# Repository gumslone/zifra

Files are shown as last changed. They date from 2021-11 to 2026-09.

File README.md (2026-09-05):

<a href="https://www.buymeacoffee.com/gumslone" target="_blank">Buy Me A Coffee</a>

# ZIFRA

**ZIFRA** is an open-source **single-tube nixie clock**: one Soviet-era **IN-12B nixie tube**
spells the time out digit by digit. Powered by an **ESP8266 (ESP8285)**, it syncs its time
over WiFi via **NTP**, keeps time offline with a **DS3231 RTC**, rings up to three alarms
with selectable melodies, and is configured from a **mobile-friendly web interface** —
no app needed. <a href="https://www.youtube.com/watch?v=uE2CU6pZ4Vk" target="_blank">Watch it in action</a>.



### Order

Want one without soldering? Check the
<a href="https://www.tindie.com/stores/gumslone/" target="_blank">gumslone store on Tindie</a> —
or build your own: the firmware, web interface and 3D-printable enclosure are all in this repo.

### Features:
- built-in RTC (real-time clock) chip for accurate time when ZIFRA is used offline.
- Network Time Protocol (NTP) for very accurate time in online mode.
- automatic summer/winter time switching (European and US daylight-saving rules).
- built-in buzzer with up to 3 alarms and selectable melodies (shake ZIFRA to mute a ringing alarm).
- night sleep window that turns the nixie tube off at night (shake to show the time for 3 minutes during sleep).
- mobile-friendly configuration web interface, served by the clock itself at
  http://zifra.local — no app, no cloud, works on any LAN.
- firmware updates over WiFi, straight from the web interface (optionally password-protected).

### Web interface

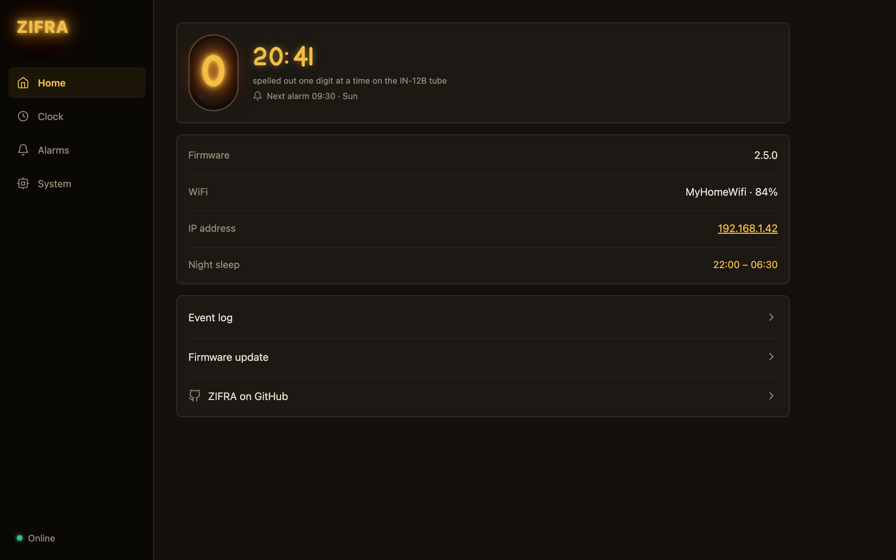
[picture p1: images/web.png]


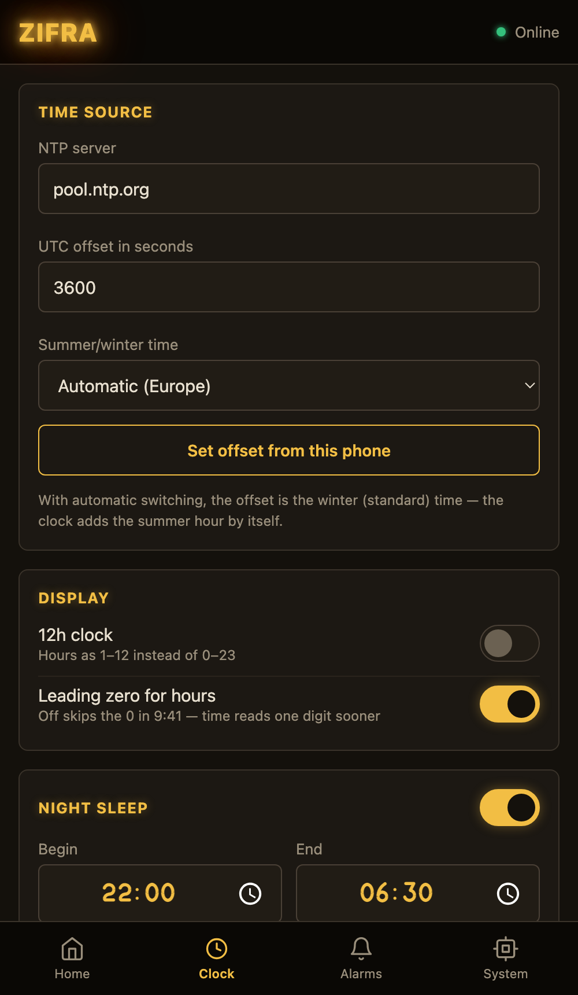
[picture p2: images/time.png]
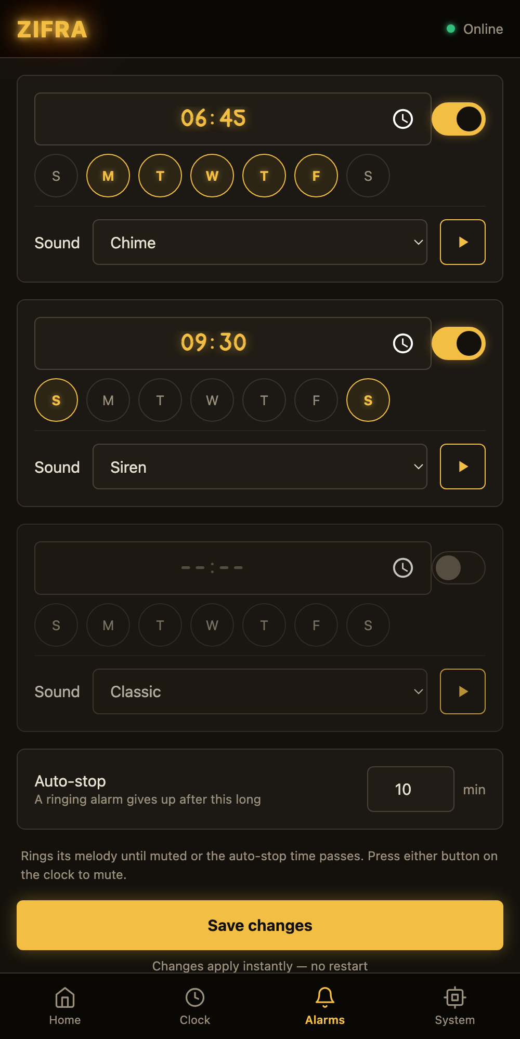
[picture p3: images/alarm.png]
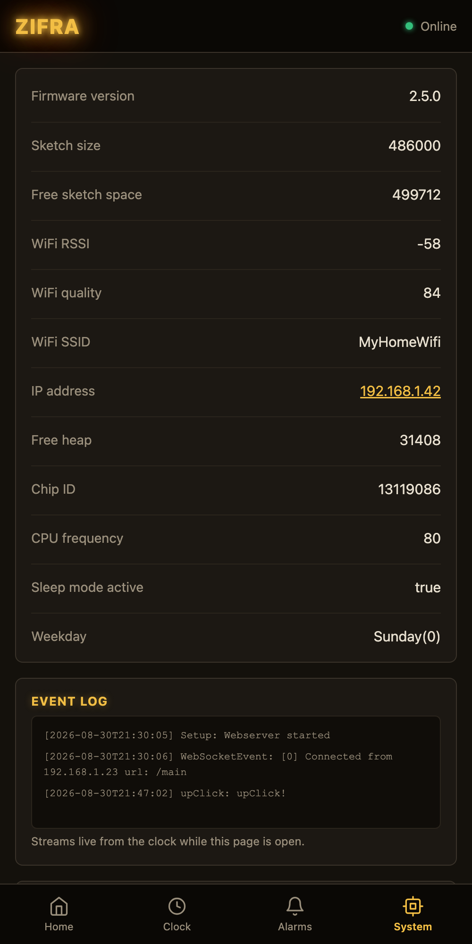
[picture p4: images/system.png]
  

### First-time setup

1. **Power the clock** with a 5 V USB power supply. On the first boot the tube cycles
   once through all digits and the buzzer plays a short jingle.
2. **Connect it to your WiFi.** With no network configured, ZIFRA opens its own
   access point named `ZIFRA-XXXXXX`. Join it with your phone and the setup portal
   opens by itself (if not, browse to `192.168.4.1`). Pick your network, enter the
   password, and save — the clock reboots and joins your WiFi. The portal stays up
   for 3 minutes; after that the clock restarts and tries again.
3. **Open the web interface** at http://zifra.local (or the clock's IP address,
   which your router's device list shows). The dashboard displays the firmware
   version, WiFi quality, IP and a live demo of what the tube is doing.
4. **Set your time zone** on the *Clock* page: tap *Set offset from this phone*, pick
   your summer/winter rule (Europe/USA) — with automatic switching on, the stored
   offset is the winter (standard) time and the clock adds the summer hour itself.
   Saving applies instantly, no restart needed.

No WiFi where the clock lives? Configure it once anywhere, then it keeps time on its
DS3231 RTC even with WiFi off.

### Everyday use

- **Reading the time** — the single tube spells the time digit by digit:
  hours' tens, hours' ones, then (with the decimal dot lit) minutes' tens and
  minutes' ones, followed by a longer dark pause before the next round. With the
  leading zero turned off, `09:41` starts straight at the `9` and reads one digit
  sooner.
- **Alarms** — up to three, each with its own weekdays and melody (preview the
  melodies right in the web UI). A ringing alarm stops when muted or after the
  configurable auto-stop time. **Shake the clock or press its button to mute.**
- **Night sleep** — the tube goes dark during the configured window (it may span
  midnight, e.g. 22:00–06:30). Shake the clock to light the time up for 3 minutes.
  The dashboard shows when the clock is asleep.
- **WiFi on/off** — shake the clock continuously for about 10 seconds to toggle
  WiFi (it restarts and runs offline from the RTC).
- **Factory reset** — hold the button for 35 seconds: settings and WiFi
  credentials are wiped and the setup portal opens again.
- **Firmware updates** — pick a release `.bin` on the *System* page and flash it
  right there, over WiFi. Settings survive updates. Set an *update password* on
  the same page if other people share your network (user name `zifra`).

### Firmware downloads

The repo ships only the stock board's release binary,
`firmware/zifra_esp8285.bin`. Every [release](https://github.com/gumslone/zifra/releases)
carries all four variants as downloadable assets:

- `zifra_esp8285_<version>.bin` — stock ZIFRA board (ESP8285)
- `zifra_esp8266_generic_<version>.bin` — generic 1M ESP8266 modules (ESP-01S, ESP-12, ...)
- `..._debug.bin` — same, with serial logging on 115200 baud

Building locally with `./build.sh all` puts all four under
`.build/<board>/<release|debug>/zifra.ino.bin`.

### Flashing over USB

For the first flash (or to recover a clock that can't reach the web updater),
ZIFRA bundles [BugZapper](https://github.com/gumslone/bugzapper) — a flasher with
a built-in serial monitor — as a git submodule under `tools/bugzapper`. esptool
is bundled, so it needs nothing but `python3`.

Clone with submodules (or pull it in afterwards):

```sh
git clone --recurse-submodules https://github.com/gumslone/zifra.git
# already cloned?
git submodule update --init
```

Then, from the repo root:

```sh
./flash.sh        # flash the bundled firmware/zifra_esp8285.bin (-f for another)
./flash.sh -l     # list detected serial ports
./bugzapper.sh    # GUI flasher + serial monitor (needs python3 with tkinter)
```

### Development

The firmware is a single Arduino sketch ([`zifra/zifra.ino`](zifra/zifra.ino)) with
its modules as headers under [`zifra/src/`](zifra/src) — pure logic (alarms, sleep
window, melodies, daylight-saving rules) is separated from hardware code so it can
be tested on the host:

```sh
./build.sh all     # arduino-cli builds: esp8285 + generic, release + debug
pio run            # or build with PlatformIO
./tests/run.sh     # native host tests (+ the web app's, if node is installed)
./tests/tidy.sh    # clang-tidy static analysis
```

Mind the flash budget: on the 1 MB layout an OTA image has to fit above the
running sketch, so a release binary bigger than about 479 KB could never be
updated over WiFi again — `build.sh` refuses to build one.

The web interface lives in [`web/v2/`](web/v2) — a dependency-free ES6 single-page
app in layered modules (`core` / `state` / `view` / `audio` / `app`). The clock
serves it itself: `tools/web/gzip_pages.py` (run by `build.sh`) bundles the JS and
CSS together with the pages in [`zifra/pages/`](zifra/pages) into gzipped PROGMEM
arrays in `Webinterface.h`, so no external hosting is involved. The same bundles
are also published at tehybug.com for firmware older than 2.5. The "Zifra Tube"
nixie webfont the UI uses is generated by
[`tools/font/build_font.py`](tools/font/build_font.py). CI builds every push and
publishes tagged releases from `zifra/src/version.h`.

### A short history of the nixie tube

Long before LEDs, numbers glowed in neon. The **nixie tube** is a cold-cathode
display from the 1950s: a glass envelope filled with neon holds a stack of ten
thin metal cathodes, each shaped like a digit, behind a wire-mesh anode. Apply
~170 V to one cathode and the gas around it ionizes — the digit is wrapped in the
soft orange glow of the neon discharge. Because the digits sit physically behind
one another, each one lights at its own depth inside the glass, which gives nixies
their unmistakable, slightly floating look.

Burroughs Corporation trademarked the name **Nixie** (from "Numeric Indicator
eXperimental No. 1") in 1955, and through the 1960s nixies were *the* readout of
serious machines: frequency counters, multimeters, desktop calculators, elevator
floor indicators, even mission-control consoles. By the mid-1970s cheaper,
lower-voltage vacuum-fluorescent displays and LEDs had displaced them in the
West — but factories in the Soviet Union kept producing their own **ИН (IN)
series** in enormous numbers well into the 1980s.

The tube in ZIFRA is one of those: the **IN-12B (ИН-12Б)**, a side-viewed nixie
with 18 mm digits and a decimal point on the left, made mainly by Reflector in
Saratov. Other IN-series tubes came from plants across the Soviet Union — the
Gazotron works in Rivne, Ukraine was among the biggest, producing the IN-8,
IN-14 and IN-16 that power many of today's nixie clocks. Unsocketed "new old stock" tubes still surface from old
warehouses, which is what keeps nixie clocks alive today — nobody mass-produces
nixies anymore, so every tube is decades old and finite. That scarcity is also why
ZIFRA uses a **single tube** that spells the time digit by digit instead of four
in a row: one tube to source, one tube to someday replace, and a clock that makes
a little ceremony out of every minute. The night-sleep window exists for the same
reason — a resting tube is a tube that lasts: powered sensibly, an IN-12B is good
for years of continuous glow, and cycling through all ten digits (as ZIFRA does at
startup) helps keep unused cathodes clean.

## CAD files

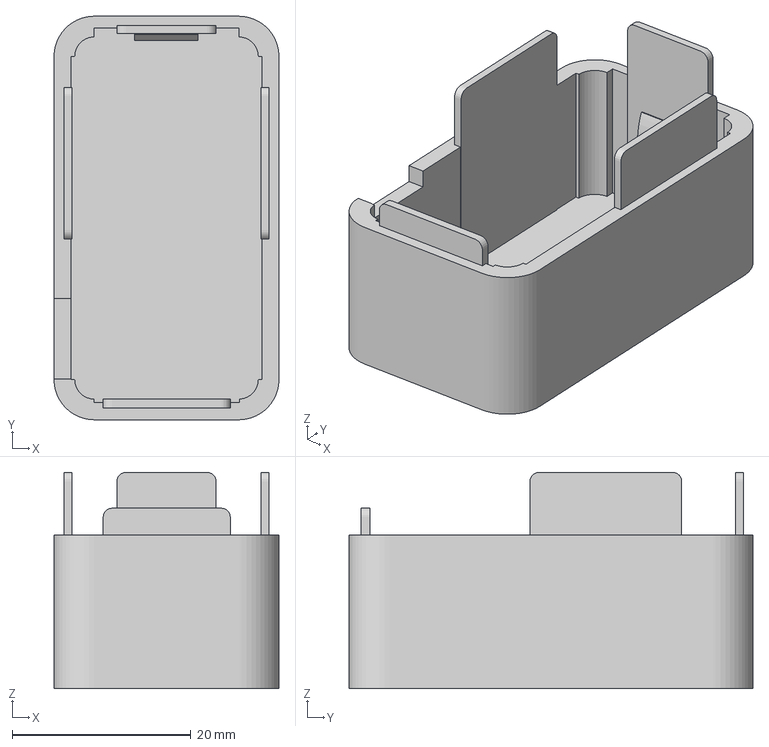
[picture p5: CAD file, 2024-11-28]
enclosure/nixie_back.3mf
25.2 x 45.2 x 24.2 mm

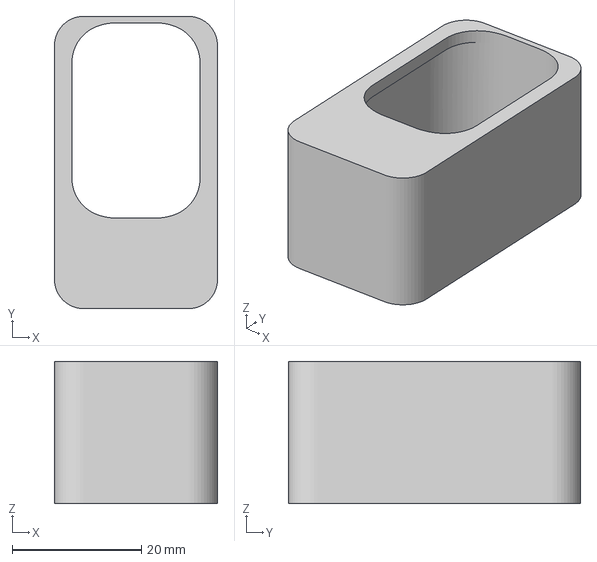
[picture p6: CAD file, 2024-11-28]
enclosure/nixie_front.3mf
25.2 x 45.2 x 22.0 mm

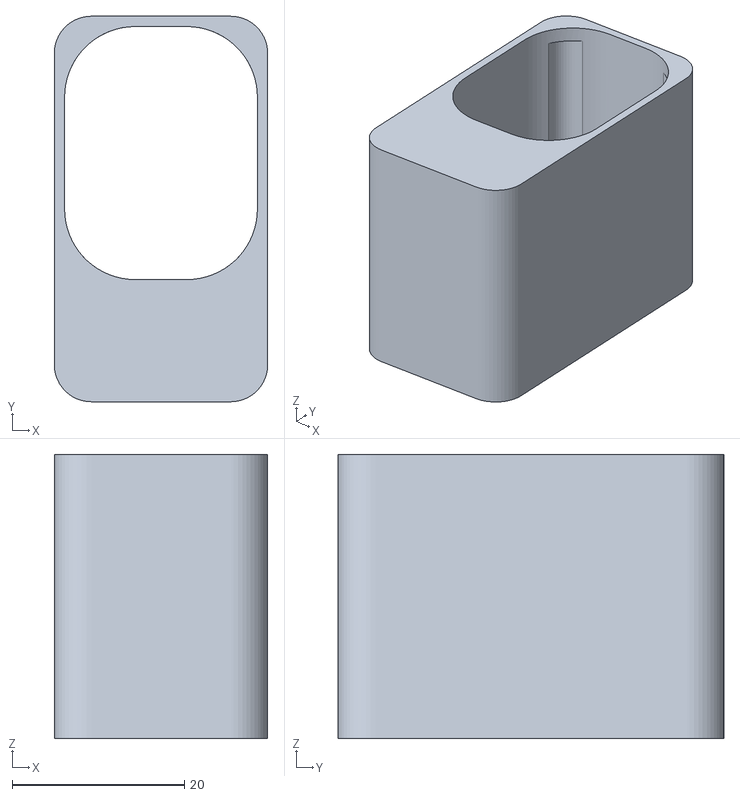
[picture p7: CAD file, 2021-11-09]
enclosure/front_v1.stl
24.8 x 44.8 x 33.0

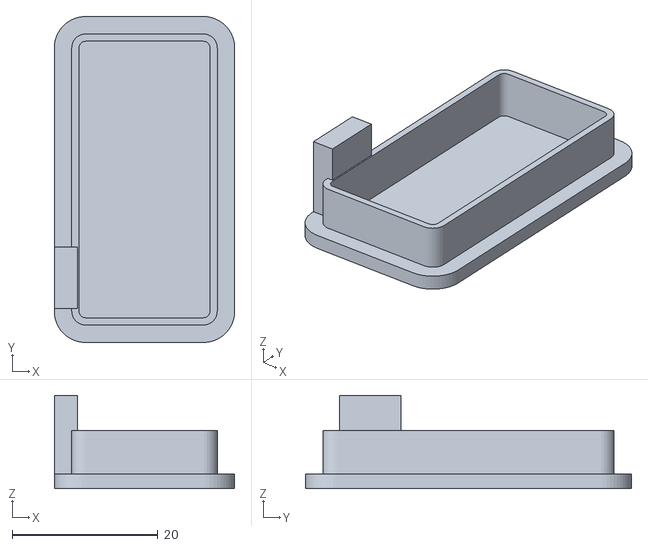
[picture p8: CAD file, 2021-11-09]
enclosure/back_v1.stl
24.8 x 44.8 x 12.8

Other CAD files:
enclosure/nixie_back.stl
enclosure/nixie_front.stl

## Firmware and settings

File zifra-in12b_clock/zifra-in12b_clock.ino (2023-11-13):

// #include <ArduinoOTA.h>
#include <ArduinoJson.h> // V5.13.5!!!
#include <ESP8266HTTPClient.h>
#include <ESP8266HTTPUpdateServer.h>
#include <ESP8266WebServer.h>
#include <ESP8266WiFi.h>
#include <ESP8266mDNS.h>
#include <EasyButton.h>
#include <FS.h>
#include <NTPClient.h>
#include <TickerScheduler.h>
#include <WebSocketsServer.h>
#include <WiFiClient.h>
#include <WiFiManager.h>
#include <WiFiUdp.h>
#include <Wire.h>
#include <ds3231.h>

#define DEBUG 1

#if DEBUG
#define D_SerialBegin(...) Serial.begin(__VA_ARGS__)
#define D_print(...) Serial.print(__VA_ARGS__)
#define D_write(...) Serial.write(__VA_ARGS__)
#define D_println(...) Serial.println(__VA_ARGS__)
#else
#define D_SerialBegin(...)
#define D_print(...)
#define D_write(...)
#define D_println(...)
#endif

#include "Tools.h"
#include "Webinterface.h"
#include "i2cscanner.h"
#include "pitches.h"
// notes in the melody:
int melody[] = {NOTE_C4, NOTE_G3, NOTE_G3, NOTE_A3,
                NOTE_G3, 0,       NOTE_B3, NOTE_C4};

// note durations: 4 = quarter note, 8 = eighth note, etc.:
int noteDurations[] = {4, 8, 8, 4, 4, 4, 4, 4};

struct ts t; // for ds2320 rtc time

char identifier[24];

// Set I2C address
int address = 0x20;

byte a = B00000000;
byte b = B00000000;

long utcOffsetInSeconds = 2 * 3600;

char daysOfTheWeek[7][12] = {"Sunday",   "Monday", "Tuesday", "Wednesday",
                             "Thursday", "Friday", "Saturday"};

uint8_t val1 = 0;
uint8_t val2 = 0;
uint8_t val3 = 0;
uint8_t val4 = 0;
uint8_t val5 = 0;
uint8_t val6 = 0;

int Year, Month, Day, Hour, Minute, Second;

// Define NTP Client to get time
String ntpServer = "pool.ntp.org";
WiFiUDP ntpUDP;
NTPClient timeClient(ntpUDP, ntpServer.c_str(), utcOffsetInSeconds);
// dns
const byte DNS_PORT = 53;
IPAddress apIP(192, 168, 4, 1);
char cmDNS[33];
String escapedMac;

// Button
#define BUTTON_PIN 0
EasyButton button(BUTTON_PIN, 40, true, true);

#define UP_BUTTON_PIN 5
EasyButton up_button(UP_BUTTON_PIN, 10, true, true);
unsigned long sleep_shake_time = 0;
//// HTTP Config

#define COMPILE_HOUR (((__TIME__[0] - '0') * 10) + (__TIME__[1] - '0'))
#define COMPILE_MINUTE (((__TIME__[3] - '0') * 10) + (__TIME__[4] - '0'))
#define COMPILE_SECOND (((__TIME__[6] - '0') * 10) + (__TIME__[7] - '0'))
#define COMPILE_YEAR                                                           \
  ((((__DATE__[7] - '0') * 10 + (__DATE__[8] - '0')) * 10 +                    \
    (__DATE__[9] - '0')) *                                                     \
       10 +                                                                    \
   (__DATE__[10] - '0'))
#define COMPILE_SHORTYEAR (((__DATE__[9] - '0')) * 10 + (__DATE__[10] - '0'))
#define COMPILE_MONTH                                                          \
  ((__DATE__[2] == 'n'   ? (__DATE__[1] == 'a' ? 0 : 5)                        \
    : __DATE__[2] == 'b' ? 1                                                   \
    : __DATE__[2] == 'r' ? (__DATE__[0] == 'M' ? 2 : 3)                        \
    : __DATE__[2] == 'y' ? 4                                                   \
    : __DATE__[2] == 'l' ? 6                                                   \
    : __DATE__[2] == 'g' ? 7                                                   \
    : __DATE__[2] == 'p' ? 8                                                   \
    : __DATE__[2] == 't' ? 9                                                   \
    : __DATE__[2] == 'v' ? 10                                                  \
                         : 11) +                                               \
   1)
#define COMPILE_DAY                                                            \
  ((__DATE__[4] == ' ' ? 0 : __DATE__[4] - '0') * 10 + (__DATE__[5] - '0'))

const String version = String(COMPILE_SHORTYEAR) + IntFormat(COMPILE_MONTH) +
                       IntFormat(COMPILE_DAY) + IntFormat(COMPILE_HOUR) +
                       IntFormat(COMPILE_MINUTE);

WiFiClient espClient;
WiFiManager wifiManager;
ESP8266WebServer server(80);
WebSocketsServer webSocket = WebSocketsServer(81);
ESP8266HTTPUpdateServer httpUpdater;

String OldInfo = ""; // old board info
// Websoket Vars
String websocketConnection[10];

bool configModeActive = true;

// System Vars
bool sleepModeActive = false;
bool shouldSaveConfig = false;

// clock
bool clock_leading_hour_zero = true; // show leading zero by default
bool clock_12h = false;              // 24h by default
bool clock_sleep = false;
String clock_sleep_start = "";
String clock_sleep_finish = "";
unsigned long clock_delay = 0;
uint8_t clock_num = 0;

uint8_t hours;
uint8_t minutes;

#define LEAP_YEAR(Y)                                                           \
  ((Y > 0) && !(Y % 4) && ((Y % 100) || !(Y % 400))) // from time-lib
char const *weekDays[] = {"Sun", "Mon", "Tue", "Wed", "Thu", "Fri", "Sat"};

// int Year, Month, Day, Hour, Minute, Second ;

TickerScheduler ticker(5);

bool DS3231_active = false;
bool wifiActive = true;

// ALARM
bool alarm_sound = true;
// alarm 1
String alarm1Time = "";
uint8_t alarm1Hour, alarm1Minute;
int alarm1Weekdays[] = {0, 0, 0, 0, 0, 0, 0};
bool alarm1Fired = false;
bool alarm1Active = false;

// alarm 2
String alarm2Time = "";
uint8_t alarm2Minute, alarm2Second;
int alarm2Weekdays[] = {0, 0, 0, 0, 0, 0, 0};
bool alarm2Fired = false;
bool alarm2Active = false;

// alarm 3
String alarm3Time = "";
uint8_t alarm3Minute, alarm3Second;
int alarm3Weekdays[] = {0, 0, 0, 0, 0, 0, 0};
bool alarm3Fired = false;
bool alarm3Active = false;

// BUTTON
//  Attach callback.

void doRestart() {
  D_println(F("5 Clicks"));
  ESP.restart();
}
void doFactoryReset() {
  D_println(F("15 Seconds Long Click"));
  Handle_factoryreset();
}

/////////////////////////////////////////////////////////////////////
int year() {
  unsigned long epochTime = timeClient.getEpochTime();

  // Get a time structure
  struct tm *ptm = gmtime((time_t *)&epochTime);

  int currentYear = ptm->tm_year + 1900;
  return currentYear;
}
int month() {
  unsigned long epochTime = timeClient.getEpochTime();

  // Get a time structure
  struct tm *ptm = gmtime((time_t *)&epochTime);

  int currentMonth = ptm->tm_mon + 1;
  return currentMonth;
}
int day() {
  unsigned long epochTime = timeClient.getEpochTime();

  // Get a time structure
  struct tm *ptm = gmtime((time_t *)&epochTime);

  int monthDay = ptm->tm_mday;
  return monthDay;
}
int hour() { return timeClient.getHours(); }
int minute() { return timeClient.getMinutes(); }
int second() { return timeClient.getSeconds(); }

void createDateElements(const char *str) {
  sscanf(str, "%d-%d-%dT%d:%d", &Year, &Month, &Day, &Hour, &Minute);
}
void createWeekdaysElements(const char *str, int *arr) {
  sscanf(str, "%d,%d,%d,%d,%d,%d,%d", &arr[0], &arr[1], &arr[2], &arr[3],
         &arr[4], &arr[5], &arr[6]);
}

void SaveConfigCallback() { shouldSaveConfig = true; }

void SaveConfig() {
  // save the custom parameters to FS
  if (shouldSaveConfig) {
    DynamicJsonDocument json(1024);

    json["utcOffsetInSeconds"] = utcOffsetInSeconds;

    json["sleepModeActive"] = sleepModeActive;

    json["ntpServer"] = ntpServer;

    json["clock_12h"] = clock_12h;

    json["clock_leading_hour_zero"] = clock_leading_hour_zero;

    json["clock_sleep"] = clock_sleep;
    json["clock_sleep_start"] = clock_sleep_start;
    json["clock_sleep_finish"] = clock_sleep_finish;

    json["alarm1Weekdays"] = join(alarm1Weekdays, ",", 7);
    json["alarm2Weekdays"] = join(alarm2Weekdays, ",", 7);
    json["alarm3Weekdays"] = join(alarm3Weekdays, ",", 7);

    json["alarm1Active"] = alarm1Active;
    json["alarm2Active"] = alarm2Active;
    json["alarm3Active"] = alarm3Active;

    json["alarm1Time"] = alarm1Time;
    json["alarm2Time"] = alarm2Time;
    json["alarm3Time"] = alarm3Time;

    json["wifiActive"] = wifiActive;

    File configFile = SPIFFS.open("/config.json", "w");
    serializeJson(json, configFile);
    configFile.close();
    D_println("SaveConfig: Saved");
    // end save
  }
}

void setConfigParameters(JsonObject &json) {

  D_println("Config:");
  for (JsonPair kv : json) {
    D_print(kv.key().c_str());
    D_print(" = ");
    D_println(kv.value().as<String>());
  }
  D_println();
  if (json.containsKey("sleepModeActive")) {
    sleepModeActive = json["sleepModeActive"];
  }
  if (json.containsKey("utcOffsetInSeconds")) {
    utcOffsetInSeconds = json["utcOffsetInSeconds"];
  }
  if (json.containsKey("ntpServer")) {
    ntpServer = json["ntpServer"].as<String>();
  }

  if (json.containsKey("clock_12h")) {
    clock_12h = json["clock_12h"];
  }

  if (json.containsKey("clock_leading_hour_zero")) {
    clock_leading_hour_zero = json["clock_leading_hour_zero"];
  }
  if (json.containsKey("clock_sleep")) {
    clock_sleep = json["clock_sleep"];
  }
  if (json.containsKey("clock_sleep_start")) {
    clock_sleep_start = json["clock_sleep_start"].as<String>();
  }
  if (json.containsKey("clock_sleep_finish")) {
    clock_sleep_finish = json["clock_sleep_finish"].as<String>();
  }

  // alarm
  if (json.containsKey("alarm1Weekdays")) {
    createWeekdaysElements(json["alarm1Weekdays"], alarm1Weekdays);
  }
  if (json.containsKey("alarm1Active")) {
    alarm1Active = json["alarm1Active"];
  }
  if (json.containsKey("alarm1Time")) {
    alarm1Time = json["alarm1Time"].as<String>();
  }

  if (json.containsKey("alarm2Weekdays")) {
    createWeekdaysElements(json["alarm2Weekdays"], alarm2Weekdays);
  }
  if (json.containsKey("alarm2Active")) {
    alarm2Active = json["alarm2Active"];
  }
  if (json.containsKey("alarm2Time")) {
    alarm2Time = json["alarm2Time"].as<String>();
  }

  if (json.containsKey("alarm3Weekdays")) {
    createWeekdaysElements(json["alarm3Weekdays"], alarm3Weekdays);
  }
  if (json.containsKey("alarm3Active")) {
    alarm3Active = json["alarm3Active"];
  }
  if (json.containsKey("alarm3Time")) {
    alarm3Time = json["alarm3Time"].as<String>();
  }

  if (json.containsKey("wifiActive")) {
    wifiActive = json["wifiActive"];
  }
}

void LoadConfig() {
  if (SPIFFS.exists("/config.json")) {
    // file exists, reading and loading
    File configFile = SPIFFS.open("/config.json", "r");

    if (configFile) {
      D_println("opened config file");

      DynamicJsonDocument json(1024);
      auto error = deserializeJson(json, configFile);

      if (!error) {
        JsonObject documentRoot = json.as<JsonObject>();
        setConfigParameters(documentRoot);
        D_println("LoadConfig: Loaded");
      }
    }
  } else {
    D_println("LoadConfig: No Configfile, init new file");
    SaveConfigCallback();
    SaveConfig();
  }
}

void SetConfig(JsonObject &json) {

  if (json.containsKey("utcOffsetInSeconds")) {
    utcOffsetInSeconds = json["utcOffsetInSeconds"];
    timeClient.setTimeOffset(utcOffsetInSeconds);
    if (DS3231_active) {
      t.hour = timeClient.getHours();
      t.min = timeClient.getMinutes();
      t.sec = timeClient.getSeconds();
      t.mday = day();
      t.mon = month();
      t.year = year();
      DS3231_set(t);
    }
  }
  setConfigParameters(json);
  SaveConfigCallback();
  SaveConfig();

  delay(1000);
  ESP.restart();
}

void WifiSetup() {
  wifiManager.resetSettings();
  ESP.restart();
  delay(300);
}

void HandleGetMainPage() {
  server.sendHeader("Connection", "close");
  server.send(200, "text/html", mainPage);
}

#pragma region //////////////////////////// HTTP API
///////////////////////////////
void HandleNotFound() {
  if (server.method() == HTTP_OPTIONS) {
    server.sendHeader("Access-Control-Allow-Origin", "*");
    server.send(204);
  }

  server.sendHeader("Location", "/update", true);
  server.send(302, "text/plain", "");
}
void HandleGetConfig() {
  server.sendHeader("Connection", "close");
  server.send(200, "application/json", GetConfig());
}
void Handle_wifisetup() { WifiSetup(); }
void Handle_factoryreset() {
  File configFile = SPIFFS.open("/config.json", "w");
  if (!configFile) {
    Log("Handle_factoryreset", "Failed to open config file for reset");
  }
  configFile.println("");
  configFile.close();
  WifiSetup();
  ESP.restart();
}
void SendConfig() {
  if (webSocket.connectedClients() > 0) {
    for (int i = 0;
         i < sizeof websocketConnection / sizeof websocketConnection[0]; i++) {
      if (websocketConnection[i] == "/settings" ||
          websocketConnection[i] == "/settime" ||
          websocketConnection[i] == "/setalarm" ||
          websocketConnection[i] == "/setsystem"

      ) {
        String config = GetConfig();
        webSocket.sendTXT(i, config);
      }
    }
  }
}
String GetConfig() {
  File configFile = SPIFFS.open("/config.json", "r");

  if (configFile) {
    Log(F("GetConfig"), F("Opened config file"));
    size_t size = configFile.size();
    // Allocate a buffer to store contents of the file.
    std::unique_ptr<char[]> buf(new char[size]);

    configFile.readBytes(buf.get(), size);
    DynamicJsonDocument root(1024);
    if (DeserializationError::Ok == deserializeJson(root, buf.get())) {
    }

    String json;
    serializeJson(root, json);

    return json;
  }
  return "";
}

/////////////////////////////////////////////////////////////////////
void Log(String function, String message) {

  String timeStamp = IntFormat(year()) + "-" + IntFormat(month()) + "-" +
                     IntFormat(day()) + "T" + IntFormat(hour()) + ":" +
                     IntFormat(minute()) + ":" + IntFormat(second());

  D_println("[" + timeStamp + "] " + function + ": " + message);

  // Prüfen ob über Websocket versendet werden muss
  if (webSocket.connectedClients() > 0) {
    for (int i = 0;
         i < sizeof websocketConnection / sizeof websocketConnection[0]; i++) {
      if (websocketConnection[i] == "/main") {
        webSocket.sendTXT(i, "{\"log\":{\"timeStamp\":\"" + timeStamp +
                                 "\",\"function\":\"" + function +
                                 "\",\"message\":\"" + message + "\"}}");
      }
    }
  }
}

String GetInfo() {
  DynamicJsonDocument root(1024);

  root["gumboardVersion"] = version;
  root["sketchSize"] = ESP.getSketchSize();
  root["freeSketchSpace"] = ESP.getFreeSketchSpace();
  root["wifiRSSI"] = String(WiFi.RSSI());
  root["wifiQuality"] = GetRSSIasQuality(WiFi.RSSI());
  root["wifiSSID"] = WiFi.SSID();
  root["ipAddress"] = WiFi.localIP().toString();
  root["freeHeap"] = ESP.getFreeHeap();
  root["chipID"] = ESP.getChipId();
  root["cpuFreqMHz"] = ESP.getCpuFreqMHz();
  root["clock_sleep"] = clock_sleep;

  int DoW = dayOfWeek(year(), month(), day());
  String week_day;
  switch (DoW) {
  case 0:
    week_day = "Saturday";
    break;
  case 1:
    week_day = "Sunday";
    break;
  case 2:
    week_day = "Monday";
    break;
  case 3:
    week_day = "Tuesday";
    break;
  case 4:
    week_day = "Wednesday";
    break;
  case 5:
    week_day = "Thursday";
    break;
  case 6:
    week_day = "Friday";
    break;
  }
  
  root["weekday"] = week_day;
  String json;
  serializeJson(root, json);

  return json;
}

void SendInfo(bool force) {
  String Info;

  // Prüfen ob die ermittlung der MatrixInfo überhaupt erforderlich ist
  if ((webSocket.connectedClients() > 0)) {
    Info = GetInfo();
  }

  // Prüfen ob über Websocket versendet werden muss
  if (webSocket.connectedClients() > 0 && OldInfo != Info) {
    for (int i = 0;
         i < sizeof websocketConnection / sizeof websocketConnection[0]; i++) {
      if (websocketConnection[i] == "/main" ||
          websocketConnection[i] == "/api/info") {
        webSocket.sendTXT(i, Info);
      }
    }
  }
  OldInfo = Info;
}
#pragma region //////////////////////////// Websocket
///////////////////////////////

void webSocketEvent(uint8_t num, WStype_t type, uint8_t *payload,
                    size_t length) {

  switch (type) {
  case WStype_DISCONNECTED: {
    Log("WebSocketEvent", "[" + String(num) + "] Disconnected!");
    websocketConnection[num] = "";
    break;
  }
  case WStype_CONNECTED: {
    // Merken für was die Connection hergstellt wurde
    websocketConnection[num] = String((char *)payload);

    // IP der Connection abfragen
    IPAddress ip = webSocket.remoteIP(num);

    // Logausgabe
    Log("WebSocketEvent", "[" + String(num) + "] Connected from " +
                              ip.toString() +
                              " url: " + websocketConnection[num]);

    // send message to client
    SendInfo(true);
    SendConfig();
    break;
  }
  case WStype_TEXT: {
    if (((char *)payload)[0] == '{') {
      DynamicJsonDocument json(512);

      deserializeJson(json, payload);

      // Logausgabe
      Log("WebSocketEvent",
          "Incomming Json length: " + String(measureJson(json)));

      if (websocketConnection[num] == "/setConfig") {
        JsonObject object = json.as<JsonObject>();
        SetConfig(object);
      }
    }
    break;
  }
  case WStype_BIN:
    // Serial.printf("[%u] get binary length: %u\n", num, length);
    // hexdump(payload, length);

    // send message to client
    // webSocket.sendBIN(num, payload, length);
    break;
  }
}
#pragma endregion

/////////////////////////////////////////////////////////////////////
// alarm
void playAlarm() {
  if (alarm1Fired || alarm2Fired || alarm3Fired) {
    if (alarm_sound)
      tone(4, 780, 180);
    else
      tone(4, 500, 180);
    alarm_sound = !alarm_sound;
  }
}
void handleAlarm() {

  String currentTime =
      IntFormat(hour()) + ":" + IntFormat(minute()) + ":" + IntFormat(second());
  String chekAlarm1Time = alarm1Time + ":00";
  String chekAlarm2Time = alarm2Time + ":00";
  String chekAlarm3Time = alarm3Time + ":00";
  byte NumDayOfWeek = dayOfWeek(year(), month(), day());
  if (chekAlarm1Time == currentTime && alarm1Active == true &&
      alarm1Weekdays[NumDayOfWeek] == 1) {
    alarm1Fired = true;
    D_println(F("ALARM 1!"));
  } else if (chekAlarm2Time == currentTime && alarm2Active == true &&
             alarm2Weekdays[NumDayOfWeek] == 1) {
    alarm2Fired = true;
    D_println(F("ALARM 2!"));
  } else if (chekAlarm3Time == currentTime && alarm3Active == true &&
             alarm3Weekdays[NumDayOfWeek] == 1) {
    alarm3Fired = true;
    D_println(F("ALARM 3!"));
  }

  playAlarm();
}

void handleMuteAlarms() {
  alarm1Fired = false;
  alarm2Fired = false;
  alarm3Fired = false;

  noTone(4);
}
// BUTTON
//  Attach callback.
void singleClick() {
  handleMuteAlarms();
  tone(4, NOTE_C4, 1000 / 16);
  // stop the tone playing:
  delay(200);
  noTone(4);
  D_println(F("singleClick"));
  Log(F("singleClick"), F("singleClick!"));
}
void upClick() {
  sleep_shake_time = millis();
  handleMuteAlarms();
  tone(4, NOTE_C4, 1000 / 16);
  // stop the tone playing:
  delay(200);
  noTone(4);
  D_println(F("upClick"));
  Log(F("upClick"), F("upClick!"));
}
void toggleWifi() {
  wifiActive = !wifiActive;
  SaveConfigCallback();
  SaveConfig();
  delay(1000);
  ESP.restart();
}
// CLOCK
//  Function for writing two Bytes to the I2C expander device
void pf575_write(uint16_t data) {
  Wire.beginTransmission(address);
  Wire.write(lowByte(data));
  Wire.write(highByte(data));
  Wire.endTransmission();
}

uint8_t hi, lo;
uint16_t pcf8575_read() {
  Wire.beginTransmission(address);
  Wire.endTransmission();

  Wire.requestFrom(address, 2);
  if (Wire.available()) {
    lo = Wire.read();
    hi = Wire.read();
    return (word(hi, lo)); // joing bytes
  }
  return 0;
}

// turn all ports off
void turn_all_off() {
  // turn all off
  a = B00000000;
  b = B00000000;
  pf575_write(word(a, b));
}

void turn_on() {
  byte c, d;
  c = a;
  d = b;
  // turn on
  for (int i = 0; i < 50; i++) {
    // Set port on
    pf575_write(word(c, d));
  }
}

void show_number(int num, bool dot = false) {
  if (dot == true) {
    bitSet(a, 2); // dot pin
  }
  if (num < 8) {
    bitSet(b, num); // 0-7 Pins
  } else {
    num = num - 8;
    bitSet(a, num); // 8-9 + dot Pins
  }
  turn_on();
  D_print(num);
}

void read_time() {

  if (wifiActive) {
    timeClient.update();
    D_print(daysOfTheWeek[timeClient.getDay()]);
    D_print(", ");
    D_print(timeClient.getHours());
    D_print(":");
    D_print(timeClient.getMinutes());
    D_print(":");
    D_println(timeClient.getSeconds());

    hours = timeClient.getHours();
    minutes = timeClient.getMinutes();
  } else {
    DS3231_get(&t);
    hours = t.hour;
    minutes = t.min;
    D_print("\t Weekday : ");
    D_print(dayOfWeek(t.year, t.mon, t.mday));
    D_print(" Date : ");
    D_print(t.mday);
    D_print("/");
    D_print(t.mon);
    D_print("/");
    D_print(t.year);
    D_print("\t Hour : ");
    D_print(t.hour);
    D_print(":");
    D_print(t.min);
    D_print(".");
    D_println(t.sec);
  }
  if (clock_12h && hours > 12) {
    hours = hours - 12;
  } else if (clock_12h && hours == 0) {
    hours = 12;
  }
  clock_num = 0;
}
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
void loop() {
  button.read();
  up_button.read();
  yield();
  if (wifiActive) {
    MDNS.update();
    server.handleClient();
    yield();
    webSocket.loop();
    yield();
  }

  ticker.update();
  yield();
}

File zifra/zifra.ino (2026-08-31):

#include <ArduinoJson.h> // V5.13.5!!!
#include <ESP8266HTTPClient.h>
#include <ESP8266HTTPUpdateServer.h>
#include <ESP8266WebServer.h>
#include <ESP8266WiFi.h>
#include <ESP8266mDNS.h>
#include <EasyButton.h>
#include <FS.h>
#include <TickerScheduler.h>
#include <WebSocketsServer.h>
#include <WiFiClient.h>
#include <WiFiManager.h>
#include <WiFiUdp.h>
#include <Wire.h>
#ifndef DEBUG
#define DEBUG 0 // can be overridden with -DDEBUG=1 (see build.sh)
#endif
#if DEBUG
#define D_SerialBegin(...) Serial.begin(__VA_ARGS__)
#define D_print(...) Serial.print(__VA_ARGS__)
#define D_write(...) Serial.write(__VA_ARGS__)
#define D_println(...) Serial.println(__VA_ARGS__)
#else
#define D_SerialBegin(...)
#define D_print(...)
#define D_write(...)
#define D_println(...)
#endif

#include "src/version.h"
#include "src/common_functions.h"
#include "src/Webinterface.h"
#include "src/i2cscanner.h"
#include "src/zifra.h"
#include "src/network.h"
#include "src/webservice.h"

char identifier[24];

// Define NTP Client to get time
WiFiUDP ntpUDP;
Zifra zifra(ntpUDP);

WiFiManager wifiManager;
Network network(wifiManager, zifra.conf);
WebService webService(zifra);

TickerScheduler ticker(5);

// Buttons
#define BUTTON_PIN 0
EasyButton button(BUTTON_PIN, 40, true, true);

#define UP_BUTTON_PIN 5
EasyButton up_button(UP_BUTTON_PIN, 10, true, true);

/////////////////////////////////////////////////////////////////////
// BUTTON callbacks
void singleClick() {
  zifra.alarm.mute();
  zifra.buzzer.beep();
  webService.log(F("singleClick"), F("singleClick!"));
}

void upClick() {
  zifra.vol.sleepShakeTime = millis();
  zifra.alarm.mute();
  zifra.buzzer.beep();
  webService.log(F("upClick"), F("upClick!"));
}

void toggleWifi() {
  zifra.conf.wifiActive = !zifra.conf.wifiActive;
  zifra.conf.saveConfig(true);
  delay(1000);
  ESP.restart();
}

void doFactoryReset() {
  File configFile = SPIFFS.open("/config.json", "w");
  if (configFile) {
    configFile.println("");
    configFile.close();
  } else {
    webService.log(F("FactoryReset"), F("Failed to open config file for reset"));
  }
  network.reset();
}

/////////////////////////////////////////////////////////////////////
void setup() {
  snprintf(identifier, sizeof(identifier), "ZIFRA-%X", ESP.getChipId());
  Wire.begin(2, 0);

  zifra.startUpNixie();

  Serial.begin(115200);
  while (!Serial)
    ;

  // Mounting FileSystem
  D_println(F("Mounting file system..."));
  if (SPIFFS.begin()) {
    D_println(F("Successfully mounted file system."));
    zifra.conf.loadConfig();
  } else {
    D_println(F("Failed to mount FS"));
  }

  i2cScanner::scan();

  if (i2cScanner::addressExists("0x68")) {
    zifra.conf.DS3231_active = true;
  }

  zifra.buzzer.startUpMelody();
  zifra.setUp();

  if (zifra.conf.wifiActive) {
    network.begin(identifier);
    webService.begin();

    delay(1000);
    zifra.time.begin();
  } else {
    // Turn off WiFi
    WiFi.mode(WIFI_OFF);
  }

  ticker.add(
  0, 100, [&](void *) {
    zifra.showTime();
  }, nullptr, true);
  ticker.add(
  1, 5500, [&](void *) {
    zifra.update();
  }, nullptr, true);
  // Live stats for the System page; skipped when nothing changed
  ticker.add(
  2, 10000, [&](void *) {
    if (zifra.conf.wifiActive) {
      webService.sendInfo();
    }
  }, nullptr, true);

  // Initialize the buttons.
  button.begin();
  button.onPressed(singleClick);
  // Factory reset after a long press.
  button.onPressedFor(35000, doFactoryReset);

  up_button.begin();
  up_button.onPressed(upClick);
  // Toggle WiFi after a 10 seconds press.
  up_button.onPressedFor(10000, toggleWifi);
}

void loop() {
  button.read();
  up_button.read();
  yield();
  if (zifra.conf.wifiActive) {
    network.loop();
    webService.loop();
    yield();
  }

  ticker.update();
  yield();
}

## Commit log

2024-08-02 bugfixes and code refactoring
    [configuration.h]
2024-08-03 cleanup, refactoring, format
    [configuration.h]
2024-11-28 v2 enclosure
    [nixie_back.3mf, nixie_back.stl, nixie_front.3mf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]
2026-06-10 refactored code, also added html files
    [configuration.h]
2026-06-10 Redesign web UI for the single-tube IN-12B clock
    Dark nixie-amber theme, a live tube demo on the dashboard that mimics
    the real digit sequence, descriptions for every setting, button cheat
    sheet, and shared partials. Also ignore local .claude tooling config.
2026-06-10 Add release workflow for merges from development to main
    Builds release and debug firmware with arduino-cli (ESP8266 core 2.7.4,
    pinned libraries) via build.sh and publishes the binaries as a GitHub
    release. Also runnable manually via workflow_dispatch.
2026-06-10 Vendor Arduino libraries used by the firmware
    Copy the exact local copies of all 7 used libraries (notably
    WebSockets 2.2.1, which is no longer in the library registry) into
    ./libraries, stripped of examples/tests. build.sh now passes them to
    arduino-cli via --libraries, so local and CI builds are identical, and
    the release workflow no longer installs libraries.
2026-06-12 Fix IN-12B details in the tube demo
    The IN-12B's decimal point sits at the lower left of the digit, not the
    right, and the bulb is equally rounded at top and bottom. Adjust the
    dashboard demo, the reading-order notation (.M instead of M.) and the
    help text, and refresh the README dashboard screenshot.
2026-08-25 Extract pure logic into standalone headers; fix sleep in 12h mode
    Move the AlarmProperties/Clock structs into zifra_types.h and the sleep
    window and alarm decision logic into sleep_logic.h / alarm_logic.h as
    free functions the firmware classes delegate to. These headers have no
    hardware or heavy includes, so they also compile on a desktop compiler
    for host tests.
    Also fixes a real bug: Zifra::sleep() compared the sleep window against
    the 12h-converted hour, so with the 12h clock enabled an evening window
    like 22:00-06:30 never started. The decision now uses ISO (24h) hours,
    like the alarms always did.
    [configuration.h]
2026-08-25 Add native host tests and clang-tidy static analysis
    tests/run.sh compiles the firmware's pure-logic headers against a
    minimal Arduino shim (std::string-backed String, controllable millis)
    and runs four suites: sleep window, alarm decisions/expiry, the nixie
    digit-slot timer, and the formatting helpers - including regression
    tests for the 12h sleep bug and the join() separator bug. tests/tidy.sh
    runs clang-tidy (clang-analyzer/bugprone/performance) over the same
    translation units; findings it caught (reserved include-guard
    identifiers, join() copying its separator) are fixed.
    [test_alarm_logic.cpp]
2026-08-25 Restructure: headers into src/, shipped binary into firmware/
    Module headers move from the sketch root into zifra/src/ (which
    arduino-cli compiles recursively; the .ino stays the single TU and now
    includes them as src/<header>.h). The shipped ESP8285 release binary
    moves to firmware/zifra_esp8285.bin, arduino-cli build output to
    .build/ at the repo root. build.sh, the BugZapper wrappers, the release
    workflow, the host-test include paths, and the README follow.
    [configuration.h]
2026-08-25 Add PlatformIO build alongside arduino-cli
    platformio.ini with esp8285 / esp8266_generic envs (plus _debug
    variants), pinned to espressif8266@2.6.3 which bundles the same Arduino
    core 2.7.4 as build.sh, building the vendored libraries via
    lib_extra_dirs. lib_ldf_mode=deep (deep+ would drop arduinoWebSockets'
    guarded ESP8266WiFi dependency). arduino-cli stays the release
    reference; binary sizes come out within ~300 bytes of it.
2026-08-28 Switch to semantic versioning (1.1.0)
    The firmware version now comes from ZIFRA_VERSION in zifra/src/version.h
    (single source of truth) instead of being derived from the compile
    date - returning to the semantic scheme of the original v1.0.x tags.
    The release workflow reads it from the header, tags releases v<version>,
    and skips publishing when the tag already exists, so every release
    requires a version bump and re-runs are idempotent. The compile-date
    macro block in the sketch is gone.
    [zifra.ino]
2026-08-28 Refresh dashboard screenshot for the 1.1.0 version scheme
    The System info sample data now shows the semantic firmware version
    instead of the old compile-date string.
2026-08-30 Web UI v2 (mobile-first) and firmware 2.0.0
    New v2 web interface at tehybug.com/zifra/v2/: a mobile-first vanilla-JS
    single-page app (34 KB total vs ~390 KB of v1 bundles) with bottom tab
    navigation on phones and a side rail on desktop - Home with a live tube
    demo and status glance, Clock, Alarms with weekday chips, and System
    with the event log and updater link. Speaks the unchanged v1 websocket
    protocol (/main, /settime, /setConfig on :81), so it works with any
    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
2026-08-30 README screenshots for the v2 web interface
    Desktop Home plus mobile Clock/Alarms/System captures of the new UI;
    the old updater screenshot is gone (that page is device-served). Also
    fixes an unsized SVG that let the updater button's icon fill the whole
    button, spotted while capturing.
2026-08-30 Selectable alarm melodies; save config without restarting
    Each alarm now has a sound: Classic (the original two-tone), Double
    beep, Siren, or Chime, defined as looping note sequences in melodies.h
    and played non-blockingly on the display tick. The web UI gets a
    per-alarm sound picker with a WebAudio preview.
    Saving config no longer reboots the clock: everything is read live, and
    the one thing that was baked in at boot - the NTP offset and server -
    is now re-applied through NTPClient::setTimeOffset/setPoolServerName
    with an immediate resync (and a fresh DS3231 write). The firmware also
    pushes the saved config back to connected settings pages as
    confirmation. Version 2.1.0.
    [configuration.h]
2026-08-30 Configurable alarm auto-stop timeout
    The ringing timeout was a hardcoded 10 minutes; it is now
    alarmTimeoutMinutes in the config (clamped to at least 1), with an
    Auto-stop field on the web UI's Alarms screen. Version 2.3.0.
    [configuration.h]
2026-08-30 README: keyword-rich intro and Tindie order link
    Describe what ZIFRA is (single-tube IN-12B nixie clock, ESP8266, NTP,
    DS3231, alarms, mobile web UI) instead of a one-liner, and link the
    Tindie store. Repo description and topics updated on GitHub to match.
2026-08-30 Zifra Tube: a custom nixie-style digit webfont for the v2 UI
    Generated by tools/font/build_font.py: glyph skeletons of lines and
    arcs (like bent IN-12B cathode wire) are sampled into round-capped
    stroke outlines with fontTools. Just the glyphs the clock UI shows
    (0-9 : - . and dashes), 11 KB as WOFF, embedded base64 in the CSS so
    the cross-origin page needs no CORS-gated font fetch. Applied to the
    tube digit, hero time, alarm times and time inputs; the log console
    stays Courier since the font has no letters. README screenshots
    refreshed.
2026-08-30 Match the font to real IN-12 digit shapes
    From tube reference photos: 1 is a plain vertical wire (no flag), 3 is
    the Soviet flat-top form (bar, diagonal to the waist, bottom bowl), and
    all digits share one advance width so times are tabular like a tube's
    fixed anode. Screenshots refreshed.
2026-08-30 Curve the 7's stem like the reference tubes
2026-08-30 Refine 2, 4, 5 and 9 against tube reference photos
    Two iterations compared side by side with the reference digit grid:
    the 2 gets a narrower round head and steeper straight diagonal, the 4
    becomes the apex-topped form with a longer crossbar, the 5 flows from
    a short bar into a bigger rounder belly, and the 9's tail reaches
    closer to the baseline.
2026-08-30 Trace the digit shapes from the tube reference
    Hand-drawn skeletons never quite matched, so trace_ref.py now extracts
    each digit's bright core from a reference photo, skeletonizes it to
    its medial axis, and stores the paths in traced_skeletons.json - the
    build renders those real shapes with its own uniform round stroke. The
    4 keeps the clean hand skeleton (its crossing junctions trace badly).
2026-08-30 Best-of-both digit set; keep reLix as reference only
    Round digits (0, 6, 8, 9) and the 1 and 4 return to clean geometric
    skeletons - the photo traces wobbled there - while 2, 3, 5 and 7 keep
    their traced reference shapes. reLix from the Analog Digits pack was
    evaluated but stays a reference: its license bars redistributing font
    files, so nothing of it ships in the repo or the bundle.
2026-08-30 Dashboard shows when the tube is asleep
    The Night sleep row now says 'asleep until HH:MM' while the clock is
    inside its sleep window (same wrap-past-midnight logic as the
    firmware), and the tube demo goes dark for the duration - like the
    real tube.
2026-08-30 Fix websocket slot exhaustion; smooth 6 and 9; no-cache bundles
    Diagnosed against a real clock: lingering half-closed sockets exhausted
    the websocket server's 5 client slots, so new /settime connections were
    refused (the UI then showed default config - 'Night sleep: off') and
    every broadcast stalled up to 10 s on writes to dead peers. The server
    now pings clients and drops dead ones (enableHeartbeat), and sends info
    plus config directly to every connecting client whatever its path, so
    one socket suffices. Verified on-device: connects in 0.09 s, config in
    0.1 s (was: refused / 10.6 s).
    Also: the 6 and 9 are rebuilt as tangent-continuous double arcs (exact
    180-degree rotations of each other),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
    [zifra.ino]
2026-08-30 Restore the clean geometric flat-top 3
    The traced 3 wobbled; only 2, 5 and 7 keep traced shapes now.
2026-08-30 Flatten the horizontal bars of 2, 5 and 7
    The trace kept the rounded stroke tips, so the bars drooped a few
    units at their ends; snap every point on a bar to its exact y.
2026-08-30 Narrow the 1 and the colon
    The bare-wire 1 and the colon dots sat centered in full tube-width
    advances, leaving big holes on both sides in times like 01:12; give
    them proportional 340-unit advances instead.
2026-08-30 Shorten the 1 to the digits' optical height
    The round stroke caps extend 48 units past each endpoint, so the
    full-height wire stood taller than every other digit; pull its
    endpoints in to 655/45.
2026-08-30 Add automatic summer/winter time switching (2.4.0)
    A new dstMode setting (off / EU rules / US rules) adds the summer
    hour on top of the configured standard UTC offset; the switch dates
    are computed from the NTP time, host-tested against the 2025/2026
    boundary instants. The phone-offset button stores the winter offset
    when automatic switching is on.
    [configuration.h]
2026-08-31 Mirror 12h and leading-zero settings in the dashboard demo
    The hero time and the tube demo now show the hours exactly as the
    firmware displays them: 12h conversion, and with the leading zero off
    the first digit's slots are skipped like on the real tube. Both react
    immediately when the display toggles change.
2026-08-31 Restructure the firmware into src modules
    zifra.ino shrinks to globals, buttons, setup and loop; WiFi/mDNS live
    in src/network.h (class Network) and the HTTP server, OTA updater and
    websocket API in src/webservice.h (class WebService). The System page
    gets a periodic info broadcast again - sendInfo had lost its only call
    site - diffed against the last payload so idle ticks cost nothing.
    Older headers cleaned up: header guards unified, dead PF595::read
    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
    [configuration.h]
2026-08-31 Rebuild the v2 web app as layered ES6 modules
    One 684-line file becomes five modules bundled in order by
    javascript.php: core (constants, time math, event bus), state (a
    FIELDS schema drives defaults, parsing, form binding and the config
    payload - a new setting is one schema line plus markup), view
    (template-literal screens generated from a SCREENS list), audio and
    app (websockets, wiring, boot). The stylesheet splits the same way
    into base/components/nixie. Markup, behavior and the websocket
    protocol are unchanged - verified by screen captures and a config
    round-trip through the 12h editors.
2026-09-05 Web app: 12h alarm editor, clock-reported time, update password
    The alarm times get the same hour/minute/AM-PM editor as the sleep
    window in 12h mode, and flipping the 12h switch converts every time
    editor in place. The dashboard hero and tube demo now follow the
    time the clock itself reports (info.clockTime) instead of the phone's,
    so a wrong offset shows up right away. New System card to set or
    remove the firmware-update password (write-only in the protocol).
2026-09-05 Firmware 2.5.0: embedded web UI, UTC in the RTC, update password
    The clock now serves the web app itself (/, /app.js, /app.css as
    gzipped PROGMEM generated by tools/web/gzip_pages.py, run by build.sh)
    - no external hosting, versioned URLs cached for good. The DS3231
    keeps UTC and gets the offset and summer hour applied on read, so an
    offline clock switches DST correctly; it is synced from NTP after the
    first sync and daily. Config JSON parsing grows to a 1024-byte pool
    with an error check, log frames escape their text, info carries the
    displayed time (clockTime), and an optional update password guards
    /update (user 'zifra', never echoed to the UI).
    Flash budget: an OTA image on a 1MB board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
    [configuration.h]
2026-09-05 Guard the OTA size ceiling, test the web app, fix next-alarm lookahead (2.5.2)
    build.sh now refuses a release binary above 479,232 bytes - the
    largest image a 1MB board can still update over WiFi - and prints
    each size. CI regenerates Webinterface.h and fails if the committed
    copy is stale. New Node tests cover the web app's time math and
    config schema (tests/run.sh runs them, tests.yml sets up Node); they
    caught nextAlarm ignoring an alarm that already rang today, which
    now looks a full week ahead. CSS minification also drops spaces
    around punctuation (-200 bytes gzipped).
2026-09-05 Pin the gzip OS header byte so the generated UI is platform-independent
    Python writes 0xff there on macOS and 0x03 on Linux; everything else
    was already deterministic. Regenerated and rebuilt - the shipped
    binary is now byte-identical to the CI-built release asset.
